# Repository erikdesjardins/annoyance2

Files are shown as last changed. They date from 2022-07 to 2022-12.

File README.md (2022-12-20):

# annoyance2

Digital musical tesla coil interrupter

Digital version of https://github.com/erikdesjardins/annoyance. Intended to run on a "blue pill" [STM32F103C8](https://www.st.com/resource/en/datasheet/stm32f103c8.pdf) board.

## Setup

Add the target corresponding to Cortex-M3:

```sh
rustup target add thumbv7m-none-eabi
```

Install tools for linking/flashing:

```sh
cargo install flip-link probe-run
```

Follow `probe-rs` docs to install drivers for flashing:

https://probe.rs/docs/getting-started/probe-setup/

## Development

### Run on device

```sh
# use `debug` or `trace` for more info
set DEFMT_LOG=info

cargo run --manifest-path firmware/Cargo.toml --target thumbv7m-none-eabi
```

### Run with visualizer

```sh
cargo run --manifest-path firmware/Cargo.toml --target thumbv7m-none-eabi --release | cargo run --manifest-path visualizer/Cargo.toml --release
```

### Misc

```
cargo objdump --release --bin main -- --disassemble --no-show-raw-insn --print-imm-hex
```

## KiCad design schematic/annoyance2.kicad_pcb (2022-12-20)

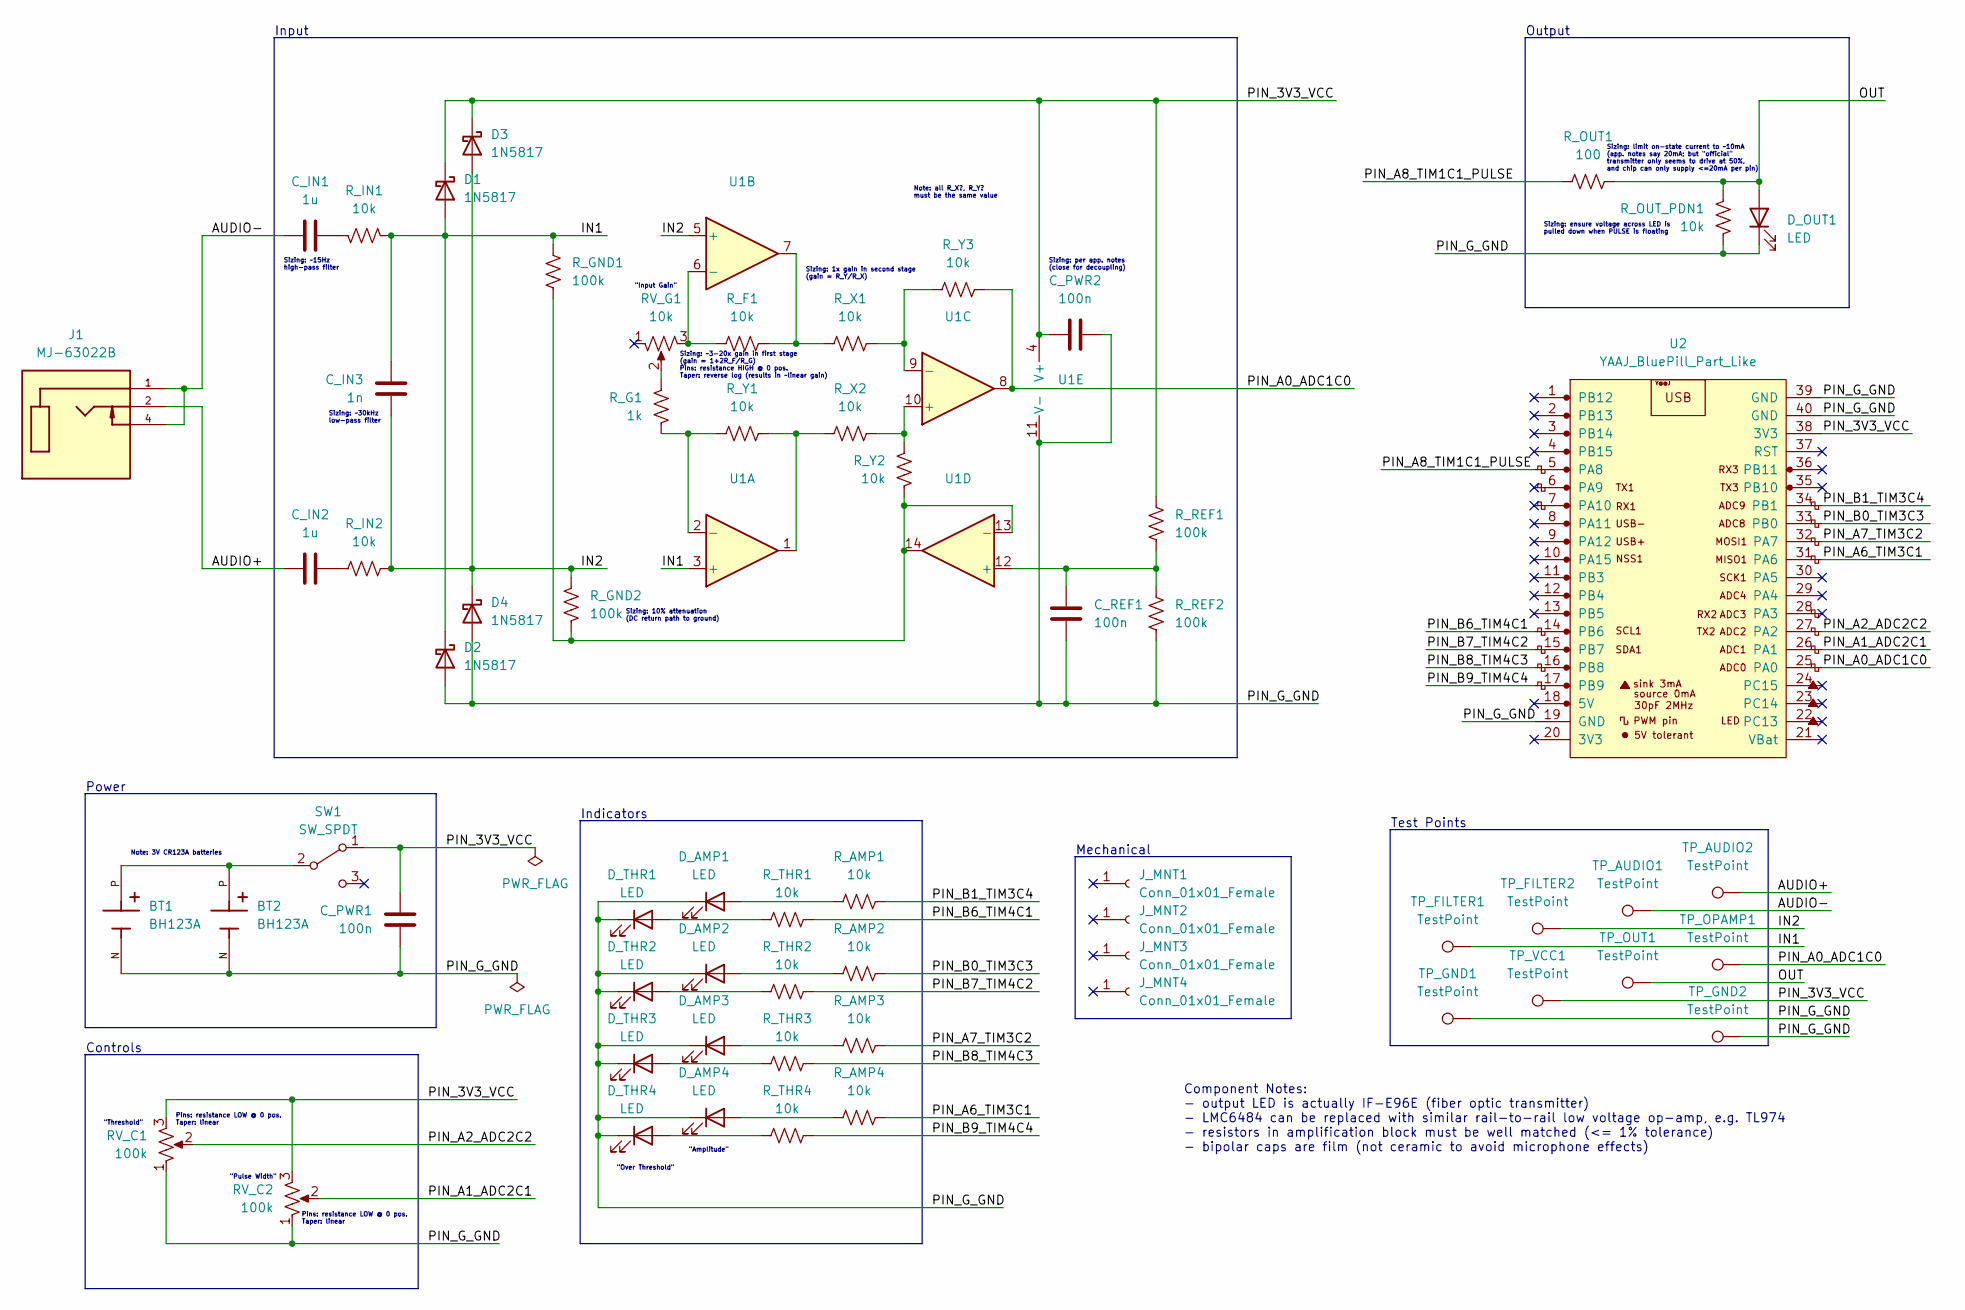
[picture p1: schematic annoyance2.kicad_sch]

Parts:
BT1, BT2: BH123A; BAT_BH123A; PARTREV E
C_IN1, C_IN2: 1u; C_Rect_L7.2mm_W5.5mm_P5.00mm_FKS2_FKP2_MKS2_MKP2
C_IN3: 1n; C_Rect_L7.2mm_W2.5mm_P5.00mm_FKS2_FKP2_MKS2_MKP2
C_PWR1, C_PWR2: 100n; C_Rect_L7.2mm_W2.5mm_P5.00mm_FKS2_FKP2_MKS2_MKP2
C_REF1: 100n; C_Rect_L7.2mm_W2.5mm_P5.00mm_FKS2_FKP2_MKS2_MKP2
D1, D2, D3, D4: 1N5817; D_DO-41_SOD81_P10.16mm_Horizontal
D_AMP1, D_AMP2, D_AMP3, D_AMP4: LED; LED_D5.0mm
D_OUT1: LED; IF-E96E
D_THR1, D_THR2, D_THR3, D_THR4: LED; LED_D5.0mm
J1: MJ-63022B; CUI_MJ-63022B; PARTREV 1.0
J_MNT1, J_MNT2, J_MNT3, J_MNT4: Conn_01x01_Female; MountingHole_3.2mm_M3_Pad
RV_C1, RV_C2: 100k; TRIM_PT01-D125D-B103
RV_G1: 10k; TRIM_PT01-D130D-A103
R_AMP1, R_AMP2, R_AMP3, R_AMP4: 10k; R_Axial_DIN0204_L3.6mm_D1.6mm_P5.08mm_Horizontal
R_F1: 10k; R_Axial_DIN0204_L3.6mm_D1.6mm_P5.08mm_Horizontal
R_G1: 1k; R_Axial_DIN0204_L3.6mm_D1.6mm_P5.08mm_Horizontal
R_GND1, R_GND2: 100k; R_Axial_DIN0204_L3.6mm_D1.6mm_P5.08mm_Horizontal
R_IN1, R_IN2: 10k; R_Axial_DIN0204_L3.6mm_D1.6mm_P5.08mm_Horizontal
R_OUT1: 100; R_Axial_DIN0204_L3.6mm_D1.6mm_P5.08mm_Horizontal
R_OUT_PDN1: 10k; R_Axial_DIN0204_L3.6mm_D1.6mm_P5.08mm_Horizontal
R_REF1, R_REF2: 100k; R_Axial_DIN0204_L3.6mm_D1.6mm_P5.08mm_Horizontal
R_THR1, R_THR2, R_THR3, R_THR4: 10k; R_Axial_DIN0204_L3.6mm_D1.6mm_P5.08mm_Horizontal
R_X1, R_X2: 10k; R_Axial_DIN0204_L3.6mm_D1.6mm_P5.08mm_Horizontal
R_Y1, R_Y2, R_Y3: 10k; R_Axial_DIN0204_L3.6mm_D1.6mm_P5.08mm_Horizontal
SW1: SW_SPDT; OS102011MA1Q
TP_AUDIO1, TP_AUDIO2: TestPoint; TestPoint_THTPad_2.0x2.0mm_Drill1.0mm
TP_FILTER1, TP_FILTER2: TestPoint; TestPoint_THTPad_2.0x2.0mm_Drill1.0mm
TP_GND1, TP_GND2: TestPoint; TestPoint_THTPad_2.0x2.0mm_Drill1.0mm
TP_OPAMP1: TestPoint; TestPoint_THTPad_2.0x2.0mm_Drill1.0mm
TP_OUT1: TestPoint; TestPoint_THTPad_2.0x2.0mm_Drill1.0mm
TP_VCC1: TestPoint; TestPoint_THTPad_2.0x2.0mm_Drill1.0mm
U1: (no value)
U2: YAAJ_BluePill_Part_Like; YAAJ_BluePill_1

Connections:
/AUDIO+: C_IN2.1, J1.2, TP_AUDIO2.1
/AUDIO-: C_IN1.1, J1.1, J1.4, TP_AUDIO1.1
/IN1: C_IN3.2, D1.2 (A), D2.1 (K), R_GND1.1, R_IN1.1, TP_FILTER1.1, U1.3 (+)
/IN2: C_IN3.1, D3.2 (A), D4.1 (K), R_GND2.1, R_IN2.2, TP_FILTER2.1, U1.5 (+)
/OUT: D_OUT1.2 (A), R_OUT1.2, R_OUT_PDN1.2, TP_OUT1.1
/PIN_3V3_VCC: C_PWR1.2, C_PWR2.1, D1.1 (K), D3.1 (K), RV_C1.3, RV_C2.3, R_REF1.1, SW1.1 (A), TP_VCC1.1, U1.4 (V+), U2.38 (3V3)
/PIN_A0_ADC1C0: R_Y3.2, TP_OPAMP1.1, U1.8, U2.25 (PA0)
/PIN_A1_ADC2C1: RV_C2.2, U2.26 (PA1)
/PIN_A2_ADC2C2: RV_C1.2, U2.27 (PA2)
/PIN_A6_TIM3C1: R_AMP4.2, U2.31 (PA6)
/PIN_A7_TIM3C2: R_AMP3.2, U2.32 (PA7)
/PIN_A8_TIM1C1_PULSE: R_OUT1.1, U2.5 (PA8)
/PIN_B0_TIM3C3: R_AMP2.2, U2.33 (PB0)
/PIN_B1_TIM3C4: R_AMP1.2, U2.34 (PB1)
/PIN_B6_TIM4C1: R_THR1.2, U2.14 (PB6)
/PIN_B7_TIM4C2: R_THR2.2, U2.15 (PB7)
/PIN_B8_TIM4C3: R_THR3.2, U2.16 (PB8)
/PIN_B9_TIM4C4: R_THR4.2, U2.17 (PB9)
/PIN_G_GND: BT1.N, BT2.N, C_PWR1.1, C_PWR2.2, C_REF1.1, D2.2 (A), D4.2 (A), D_AMP1.1 (K), D_AMP2.1 (K), D_AMP3.1 (K), D_AMP4.1 (K), D_OUT1.1 (K), D_THR1.1 (K), D_THR2.1 (K), D_THR3.1 (K), D_THR4.1 (K), RV_C1.1, RV_C2.1, R_OUT_PDN1.1, R_REF2.2, TP_GND1.1, TP_GND2.1, U1.11 (V-), U2.19 (GND), U2.39 (GND), U2.40 (GND)
unnamed: BT1.P, BT2.P, SW1.2 (B)
unnamed: C_IN1.2, R_IN1.2
unnamed: C_IN2.2, R_IN2.1
unnamed: C_REF1.2, R_REF1.2, R_REF2.1, U1.12 (+)
unnamed: D_AMP1.2 (A), R_AMP1.1
unnamed: D_AMP2.2 (A), R_AMP2.1
unnamed: D_AMP3.2 (A), R_AMP3.1
unnamed: D_AMP4.2 (A), R_AMP4.1
unnamed: D_THR1.2 (A), R_THR1.1
unnamed: D_THR2.2 (A), R_THR2.1
unnamed: D_THR3.2 (A), R_THR3.1
unnamed: D_THR4.2 (A), R_THR4.1
unnamed: RV_G1.2, R_G1.2
unnamed: RV_G1.3, R_F1.1, U1.6 (-)
unnamed: R_F1.2, R_X1.1, U1.7
unnamed: R_G1.1, R_Y1.1, U1.2 (-)
unnamed: R_GND1.2, R_GND2.2, R_Y2.1, U1.13 (-), U1.14
unnamed: R_X1.2, R_Y3.1, U1.9 (-)
unnamed: R_X2.1, R_Y1.2, U1.1
unnamed: R_X2.2, R_Y2.2, U1.10 (+)

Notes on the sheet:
Component Notes: - output LED is actually IF-E96E (fiber optic transmitter) - LMC6484 can be replaced with similar rail-to-rail low voltage op-amp, e.g. TL974 - resistors in amplification block must be well matched (<= 1% tolerance) - bipolar caps are film (not ceramic to avoid microphone effects)
Sizing: ~30kHz low-pass filter
"Over Threshold"
Controls
"Threshold"
Pins: resistance LOW @ 0 pos. Taper: linear
Input
Power
Sizing: limit on-state current to ~10mA (app. notes say 20mA; but "official" transmitter only seems to drive at 50%, and chip can only supply <=20mA per pin)
Output
Mechanical
Sizing: ensure voltage across LED is pulled down when PULSE is floating
Test Points
Indicators
Sizing: ~3-20x gain in first stage (gain = 1+2R_F/R_G) Pins: resistance HIGH @ 0 pos. Taper: reverse log (results in ~linear gain)
Sizing: ~15Hz high-pass filter
"Amplitude"
Sizing: 1x gain in second stage (gain = R_Y/R_X)
Note: all R_X?, R_Y? must be the same value
"Pulse Width"
Sizing: 10% attenuation (DC return path to ground)
Note: 3V CR123A batteries
"Input Gain"
Sizing: per app. notes (close for decoupling)

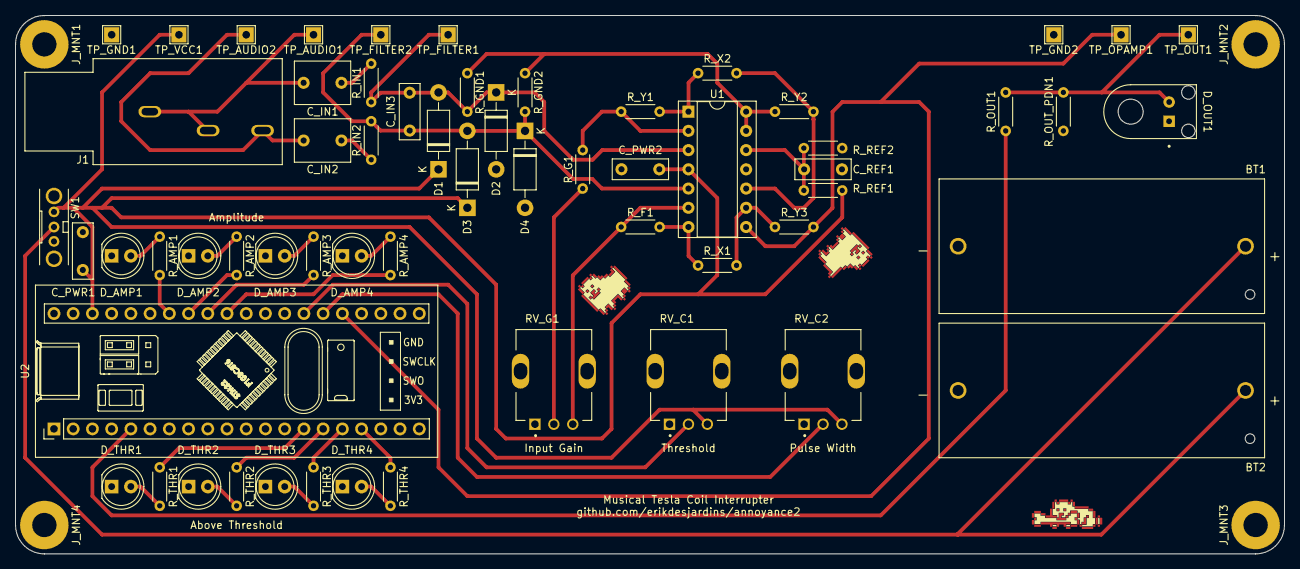
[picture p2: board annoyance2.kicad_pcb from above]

Board: 2 copper layers, 167.6 x 71.1 mm, 64 parts (0 on the bottom side), 39 nets.

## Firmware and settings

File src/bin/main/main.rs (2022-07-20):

#![no_main]
#![no_std]
#![allow(
    clippy::assertions_on_constants,
    clippy::let_and_return,
    clippy::let_unit_value,
    clippy::needless_range_loop,
    clippy::redundant_pattern_matching,
    clippy::type_complexity
)]
#![warn(
    clippy::cast_lossless,
    clippy::cast_possible_truncation,
    clippy::cast_possible_wrap,
    clippy::cast_sign_loss,
    clippy::ptr_as_ptr
)]

use annoyance2 as _; // global logger + panicking-behavior + memory layout

mod adc;
mod collections;
mod config;
mod control;
mod fft;
mod hal;
mod indicator;
mod math;
mod panic;
mod pulse;
mod time;

#[rtic::app(
    device = stm32f1xx_hal::pac,
    peripherals = true,
    dispatchers = [USART1, USART2, USART3]
)]
mod app {
    use crate::config;
    use crate::fft;
    use crate::hal::pins;
    use crate::hal::tim::{OnePulse, OneshotTimer};
    use crate::indicator;
    use crate::math::ScaleBy;
    use crate::panic::OptionalExt;
    use crate::pulse;
    use crate::pulse::{Pulses, UnadjustedPulses};
    use crate::time::{Duration, Instant, PulseDuration};
    use crate::{adc, control};
    use core::sync::atomic::{AtomicU32, Ordering};
    use cortex_m::singleton;
    use dwt_systick_monotonic::DwtSystick;
    use heapless::Vec;
    use stm32f1xx_hal::adc::{Adc, AdcDma, Continuous};
    use stm32f1xx_hal::device::{ADC1, TIM1, TIM3, TIM4};
    use stm32f1xx_hal::dma::{dma1, CircBuffer, Event};
    use stm32f1xx_hal::gpio::PinState;
    use stm32f1xx_hal::pac::ADC2;
    use stm32f1xx_hal::prelude::*;
    use stm32f1xx_hal::timer::{
        Ch, Channel::*, PwmHz, Tim1NoRemap, Tim3NoRemap, Tim4NoRemap, Timer,
    };

    static PULSE_WIDTH_TICKS: AtomicU32 = AtomicU32::new(0);

    #[shared]
    struct Shared {
        pulses: &'static mut Pulses,
    }

    #[local]
    struct Local {
        adc1_dma_transfer: CircBuffer<
            [u16; config::adc::BUF_LEN_RAW],
            AdcDma<ADC1, pins::A0_ADC1C0, Continuous, dma1::C1>,
        >,
        fft_buf: &'static mut [i16; config::fft::BUF_LEN_REAL],
        next_pulses: &'static mut UnadjustedPulses,
        adc2_controls: Adc<ADC2>,
        threshold_control_pin: pins::A2_ADC2C2,
        pulse_width_control_pin: pins::A1_ADC2C1,
        amplitude_timer: PwmHz<
            TIM3,
            Tim3NoRemap,
            (Ch<0>, Ch<1>, Ch<2>, Ch<3>),
            (
                pins::A6_TIM3C1,
                pins::A7_TIM3C2,
                pins::B0_TIM3C3,
                pins::B1_TIM3C4,
            ),
        >,
        threshold_timer: PwmHz<
            TIM4,
            Tim4NoRemap,
            (Ch<0>, Ch<1>, Ch<2>, Ch<3>),
            (
                pins::B6_TIM4C1,
                pins::B7_TIM4C2,
                pins::B8_TIM4C3,
                pins::B9_TIM4C4,
            ),
        >,
        pulse_timer:
            OnePulse<TIM1, Tim1NoRemap, Ch<0>, pins::A8_TIM1C1_PULSE, { config::clk::TIM1CLK_HZ }>,
        debug_led: pins::C13_DEBUG_LED,
    }

    #[init]
    fn init(mut cx: init::Context) -> (Shared, Local, init::Monotonics) {
        defmt::info!("Dumping config...");

        config::dump_to_log();

        defmt::info!("Starting init...");

        let mut afio = cx.device.AFIO.constrain();
        let dma1 = cx.device.DMA1.split();
        let mut flash = cx.device.FLASH.constrain();
        let mut gpioa = cx.device.GPIOA.split();
        let mut gpiob = cx.device.GPIOB.split();
        let mut gpioc = cx.device.GPIOC.split();
        let rcc = cx.device.RCC.constrain();

        defmt::info!("Configuring clocks...");

        let clocks = rcc
            .cfgr
            .use_hse(config::clk::HSE_FREQ)
            .sysclk(config::clk::SYSCLK)
            .pclk1(config::clk::PCLK1)
            .pclk2(config::clk::PCLK2)
            .adcclk(config::clk::ADCCLK)
            .freeze(&mut flash.acr);

        assert!(config::clk::SYSCLK == clocks.sysclk());
        assert!(config::clk::PCLK1 == clocks.pclk1());
        assert!(config::clk::PCLK2 == clocks.pclk2());
        assert!(config::clk::ADCCLK == clocks.adcclk());

        defmt::info!("Configuring ADC1 DMA transfer...");

        let mut dma1_ch1 = dma1.1;
        // Enable interrupts on DMA1_CHANNEL1
        dma1_ch1.listen(Event::HalfTransfer);
        dma1_ch1.listen(Event::TransferComplete);

        let mut adc1 = Adc::adc1(cx.device.ADC1, clocks);
        adc1.set_sample_time(config::adc::SAMPLE);

        let adc1_ch0: pins::A0_ADC1C0 = gpioa.pa0.into_analog(&mut gpioa.crl);

        let adc1_dma = adc1.with_dma(adc1_ch0, dma1_ch1);

        defmt::info!("Configuring ADC2 to read control values...");

        let adc2_controls = Adc::adc2(cx.device.ADC2, clocks);

        let threshold_control_pin: pins::A2_ADC2C2 = gpioa.pa2.into_analog(&mut gpioa.crl);
        let pulse_width_control_pin: pins::A1_ADC2C1 = gpioa.pa1.into_analog(&mut gpioa.crl);

        defmt::info!("Configuring amplitude indicator timer...");

        let tim3_ch4: pins::B1_TIM3C4 = gpiob.pb1.into_alternate_push_pull(&mut gpiob.crl);
        let tim3_ch3: pins::B0_TIM3C3 = gpiob.pb0.into_alternate_push_pull(&mut gpiob.crl);
        let tim3_ch2: pins::A7_TIM3C2 = gpioa.pa7.into_alternate_push_pull(&mut gpioa.crl);
        let tim3_ch1: pins::A6_TIM3C1 = gpioa.pa6.into_alternate_push_pull(&mut gpioa.crl);

        let mut amplitude_timer = Timer::new(cx.device.TIM3, &clocks).pwm_hz(
            (tim3_ch1, tim3_ch2, tim3_ch3, tim3_ch4),
            &mut afio.mapr,
            config::indicator::PWM_FREQ,
        );
        for ch in [C1, C2, C3, C4] {
            amplitude_timer.set_duty(ch, 0);
            amplitude_timer.enable(ch);
        }

        defmt::info!("Configuring threshold indicator timer...");

        let tim4_ch1: pins::B6_TIM4C1 = gpiob.pb6.into_alternate_push_pull(&mut gpiob.crl);
        let tim4_ch2: pins::B7_TIM4C2 = gpiob.pb7.into_alternate_push_pull(&mut gpiob.crl);
        let tim4_ch3: pins::B8_TIM4C3 = gpiob.pb8.into_alternate_push_pull(&mut gpiob.crh);
        let tim4_ch4: pins::B9_TIM4C4 = gpiob.pb9.into_alternate_push_pull(&mut gpiob.crh);

        let mut threshold_timer = Timer::new(cx.device.TIM4, &clocks).pwm_hz(
            (tim4_ch1, tim4_ch2, tim4_ch3, tim4_ch4),
            &mut afio.mapr,
            config::indicator::PWM_FREQ,
        );
        for ch in [C1, C2, C3, C4] {
            threshold_timer.set_duty(ch, 0);
            threshold_timer.enable(ch);
        }

        defmt::info!("Configuring pulse output timer...");

        let tim1_ch1: pins::A8_TIM1C1_PULSE = gpioa.pa8.into_alternate_push_pull(&mut gpioa.crh);

        let pulse_timer =
            OneshotTimer::new(cx.device.TIM1, &clocks).one_pulse_mode(tim1_ch1, &mut afio.mapr);

        defmt::info!("Configuring monotonic timer...");

        let mono = DwtMono::new(
            &mut cx.core.DCB,
            cx.core.DWT,
            cx.core.SYST,
            clocks.sysclk().to_Hz(),
        );

        defmt::info!("Configuring debug indicator LED...");

        let led: pins::C13_DEBUG_LED = gpioc
            .pc13
            .into_push_pull_output_with_state(&mut gpioc.crh, PinState::High);

        defmt::info!("Preparing buffers...");

        let adc_dma_buf =
            singleton!(: [[u16; config::adc::BUF_LEN_RAW]; 2] = [[0; config::adc::BUF_LEN_RAW]; 2])
                .unwrap();

        let fft_buf =
            singleton!(: [i16; config::fft::BUF_LEN_REAL] = [0; config::fft::BUF_LEN_REAL])
                .unwrap();

        let pulses = singleton!(: Pulses = Pulses::new()).unwrap();

        let next_pulses = singleton!(: UnadjustedPulses = UnadjustedPulses::new()).unwrap();

        defmt::info!("Starting ADC DMA transfer...");

        let adc1_dma_transfer = adc1_dma.circ_read(adc_dma_buf);

        defmt::info!("Finished init.");

        (
            Shared { pulses },
            Local {
                adc1_dma_transfer,
                fft_buf,
                next_pulses,
                adc2_controls,
                threshold_control_pin,
                pulse_width_control_pin,
                amplitude_timer,
                threshold_timer,
                pulse_timer,
                debug_led: led,
            },
            init::Monotonics(mono),
        )
    }

    // Task priorities
    //
    // Prio | Task         | Description
    //   16 | fire_pulse   | outputs pulses (triggered by timer interrupt)
    //   15 | DwtMono      | monotonic timer interrupt
    //   14 | swap_buffers | schedules pulse timing and processes ADC buffers
    //    0 | idle         | idle task

    /// This provides a monotonic timer used to trigger scheduled tasks.
    #[monotonic(
        binds = SysTick,
        priority = 15,
        default = true
    )]
    type DwtMono = DwtSystick<{ config::clk::SYSCLK_HZ }>;

    /// This task fires pulses.
    ///
    /// This task has the highest priority since any jitter will add phase noise to the output.
    #[task(
        shared = [
            pulses,
        ],
        local = [
            pulse_timer,
        ],
        priority = 16,
        capacity = 2 /* self + swap_buffers */,
    )]
    fn fire_pulse(mut cx: fire_pulse::Context, now: Instant) {
        cx.shared.pulses.lock(|pulses| {
            // consume this pulse (rescheduling this frequency)
            if let Err(()) = pulses.try_consume_pulse(now) {
                // if this pulse isn't present in the pulse train, our buffer was swapped,
                // and we've already been rescheduled
                defmt::trace!("pulse skipped due to in-flight buffer swap");
                return;
            }

            // load pulse width
            let pulse_width = PulseDuration::from_ticks(PULSE_WIDTH_TICKS.load(Ordering::Relaxed));

            // fire timer
            cx.local.pulse_timer.fire(pulse_width);
            if config::debug::LOG_ALL_PULSES {
                defmt::println!(
                    "Firing {}.{} us pulse at {} us",
                    pulse_width.to_nanos() / 1000,
                    pulse_width.to_nanos() % 1000,
                    Duration::from_ticks(now.ticks()).to_micros()
                );
            }

            // reschedule ourselves for the next pulse
            if let Some(next_pulse) = pulses.next_pulse(now) {
                if let Err(_) = fire_pulse::spawn_at(next_pulse, next_pulse) {
                    defmt::warn!("fire_pulse schedule overrun");
                }
            }
        });
    }

    /// This task schedules pulse timings, from the previous buffer,
    /// to be emitted while processing the current buffer.
    ///
    /// Ideally, we would like this task to have no jitter,
    /// so that timings are computed based on a consistent interval.
    ///
    /// However, this isn't perfectly feasible, since `fire_pulse` needs to be higher priority.
    ///
    /// Note that even having the highest priority would not guarantee lack of jitter:
    /// resource locks can introduce jitter when a lower-priority task takes the lock.
    #[task(
        binds = DMA1_CHANNEL1,
        shared = [
            pulses,
        ],
        local = [
            adc1_dma_transfer,
            fft_buf,
            next_pulses,
            adc2_controls,
            threshold_control_pin,
            pulse_width_control_pin,
            amplitude_timer,
            threshold_timer,
            debug_led,
        ],
        priority = 14,
    )]
    fn swap_buffers(mut cx: swap_buffers::Context) {
        cx.local.debug_led.set_low();

        // getting the timestamp must happen a consistent delay after the start of the task,
        // so timing is consistent
        let start = monotonics::now();
        // ...after this point, even if there is variable latency / jitter,
        //    everything will be scheduled off of that timestamp.

        // Note that we still need to start scheduling pulses quickly, however,
        // because delays could result in pulses being scheduled in the past.

        // Phase 1: swap in new pulse train and reschedule

        // Step 1: adjust pulses and swap
        let next_pulse = cx.shared.pulses.lock(|pulses| {
            pulses.replace_with_adjusted(cx.local.next_pulses, start);
            pulses.next_pulse(start)
        });

        // Step 2: schedule task for next pulse
        if let Some(next_pulse) = next_pulse {
            if let Err(_) = fire_pulse::spawn_at(next_pulse, next_pulse) {
                defmt::warn!("fire_pulse schedule overrun (from swap_buffers2)");
            }
        }

        let mid = monotonics::now();
        if config::debug::LOG_TIMING {
            defmt::println!(
                "Finished scheduling new pulses after {}us",
                (mid - start).to_micros()
            );
        }

        // Phase 2: update current values of controls

        // Step 1: read from controls
        let amplitude_threshold = {
            let sample = cx
                .local
                .adc2_controls
                .read(cx.local.threshold_control_pin)
                .unwrap_infallible();
            control::adc_sample_to_value_in_range(
                sample,
                config::fft::analysis::AMPLITUDE_THRESHOLD_RANGE,
            )
        };
        let pulse_width = {
            let sample = cx
                .local
                .adc2_controls
                .read(cx.local.pulse_width_control_pin)
                .unwrap_infallible();
            control::adc_sample_to_value_in_range_via(
                sample,
                config::pulse::DURATION_RANGE,
                |d| d.ticks(),
                PulseDuration::from_ticks,
            )
        };

        // Step 2: store pulse width
        PULSE_WIDTH_TICKS.store(pulse_width.ticks(), Ordering::Relaxed);

        // Step 3: log control values
        if config::debug::LOG_CONTROL_VALUES {
            defmt::println!("Amplitude threshold: {}", amplitude_threshold);
            defmt::println!(
                "Pulse width: {}.{} us",
                pulse_width.to_nanos() / 1000,
                pulse_width.to_nanos() % 1000
            );
        }

        // Phase 3: process current ADC buffer to prepare for the next swap

        let res = cx.local.adc1_dma_transfer.peek(|samples, _| {
            let scratch = cx.local.fft_buf;

            let (values, padding) = scratch.split_at_mut(config::adc::BUF_LEN_PROCESSED);
            let values: &mut [_; config::adc::BUF_LEN_PROCESSED] =
                values.try_into().unwrap_infallible();

            // Step 0: compute and display amplitude from raw samples
            let amplitude_factors = indicator::amplitude_scaling_factors(samples);
            for (factor, ch) in amplitude_factors.into_iter().zip([C4, C3, C2, C1]) {
                let duty = cx.local.amplitude_timer.get_max_duty().scale_by(factor);
                cx.local.amplitude_timer.set_duty(ch, duty);
            }

            // Step 1: populate values and padding in FFT scratch buffer
            adc::process_raw_samples(samples, values);
            padding.fill(0);

            // Step 2: apply window function to data
            fft::window::apply_to(values);

            // Step 3: run fft
            let bins = fft::run(scratch);

            // Step 4: find peaks in spectrum
            let mut peaks = Vec::new();
            fft::analysis::find_peaks(bins, amplitude_threshold, &mut peaks);

            // Step 5: compute pulses based on peaks
            pulse::schedule_pulses(&peaks, cx.local.next_pulses);

            // Step 6: compute and display "above threshold" from peaks
            let threshold_factors =
                indicator::threshold_scaling_factors(&peaks, amplitude_threshold);
            for (factor, ch) in threshold_factors.into_iter().zip([C1, C2, C3, C4]) {
                let duty = cx.local.threshold_timer.get_max_duty().scale_by(factor);
                cx.local.threshold_timer.set_duty(ch, duty);
            }
        });

        let duration = monotonics::now() - mid;
        match res {
            Ok(()) => {
                if config::debug::LOG_TIMING {
                    defmt::println!(
                        "Finished processing ADC buffer after {}us.",
                        duration.to_micros()
                    );
                }
            }
            Err(_) => {
                defmt::warn!(
                    "ADC buffer processing did not complete in time (took {}us).",
                    duration.to_micros()
                );
            }
        }

        cx.local.debug_led.set_high();
    }

    #[idle]
    fn idle(_: idle::Context) -> ! {
        loop {
            // Note that using `wfi` here breaks debugging,
            // so if desired we should only do that in release mode.
            continue;
        }
    }
}

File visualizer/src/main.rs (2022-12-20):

use crossterm::event::{Event, KeyCode, KeyModifiers};
use crossterm::terminal::{
    disable_raw_mode, enable_raw_mode, EnterAlternateScreen, LeaveAlternateScreen,
};
use crossterm::{event, execute};
use std::io::{self, BufRead};
use std::thread;
use tui::backend::CrosstermBackend;
use tui::Terminal;
use visualizer::defer;
use visualizer::err;
use visualizer::parse;
use visualizer::state::State;
use visualizer::terminal::{self, Redraw};

fn main() -> Result<(), err::DebugFromDisplay<io::Error>> {
    if atty::is(atty::Stream::Stdin) {
        eprintln!(
            r"Input must be piped into stdin.

All available commands:
.vz <id> cn <chart name>
.vz <id> sn <series name>
.vz <id> xn <x-axis name>
.vz <id> yn <y-axis name>
.vz <id> xr <x-axis min> <x-axis max>
.vz <id> yr <y-axis min> <y-axis max>
.vz <id> xs [<x coord>, ...]
.vz <id> ys [<y coord>, ...]

Note: `xr`/`yr` will automatically fit the data.
Note: `xs` doesn't need to be resent every time.

Example sequence:
.vz cn 0 FFT
.vz xn 0 Frequency
.vz yn 0 Amplitude
.vz xs 0 [0, 10, 20, 40, 80]
.vz ys 0 [10, 12, 20, 14, 8]
.vz ys 0 [11, 13, 19, 14, 7]"
        );
        return Ok(());
    }

    let stdout = io::stdout();
    let mut stdin = io::stdin().lock();

    let mut terminal = Terminal::new(CrosstermBackend::new(&stdout))?;

    thread::scope(|s| {
        // spawn a background thread to handle user input (for exiting)
        s.spawn(|| {
            let status = {
                defer! { let _ = disable_raw_mode(); }
                defer! { let _ = execute!(&stdout, LeaveAlternateScreen); }

                fn run() -> Result<(), io::Error> {
                    loop {
                        if let Event::Key(key) = event::read()? {
                            let ctrl_c = key.modifiers == KeyModifiers::CONTROL
                                && key.code == KeyCode::Char('c');
                            if ctrl_c {
                                return Ok(());
                            }
                        }
                    }
                }

                match run() {
                    Ok(()) => 0,
                    Err(e) => {
                        eprintln!("Failed to run input thread: {:?}", e);
                        1337
                    }
                }
            };

            std::process::exit(status);
        });

        let mut state = State::default();
        let mut line = String::new();

        // Wait for first line of input before we switch to the alt screen.
        // This helps in situations like `cargo run firmware | cargo run visualizer`,
        // where the firmware is still building (and hence writing to the screen),
        // so it doesn't stomp on the graph.
        if stdin.read_line(&mut line)? == 0 {
            // input stream closed
            return Ok(());
        }

        // We've seen our first line of input--switch to the alt screen and start rendering.
        enable_raw_mode()?;
        defer! { let _ = disable_raw_mode(); }
        execute!(&stdout, EnterAlternateScreen)?;
        defer! { let _ = execute!(&stdout, LeaveAlternateScreen); }
        terminal.hide_cursor()?;

        loop {
            // Parse line
            let redraw = parse::handle_line(&mut state, &line);

            // Redraw if requested
            match redraw {
                Redraw::No => {}
                Redraw::Yes => terminal::draw(&state, &mut terminal)?,
            }

            // Read next line
            line.clear();
            if stdin.read_line(&mut line)? == 0 {
                // input stream closed
                return Ok(());
            }
        }
    })
}

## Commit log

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2022-05-16 configure pwm output for use as a virtual ground at Vcc/2
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2022-05-25 tweak copying samples from input to scratch buffer
2022-05-25 add simple board schematic
    [annoyance2.kicad_pcb, annoyance2.kicad_sch]
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2022-05-25 use debug led to visualize adc buffer processing
2022-05-26 enable clippy lints related to cast/truncation and fix issues
    [adc.rs, config.rs, main.rs]
2022-05-26 introduce and use unwrap_infallible for known-correct unwraps (with optimizations)
    [adc.rs, main.rs]
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2022-05-26 fix frequency binning calculation with complex fft samples
    [adc.rs, config.rs, main.rs]
2022-05-26 tweak ADC sample rate
    ~4x lower ADC clock, slightly higher sample rate
    i hypothesize that a lower ADC clock will improve accuracy, but it's hard to tell
2022-05-26 switch protection diodes out for schottkys, per app. notes
    [annoyance2.kicad_sch]
2022-05-26 remove debug logging of final samples
    it's not that useful, now that i know it is in fact copying data correctly
    [adc.rs, config.rs]
2022-05-27 put back 1k resistor on reference voltage
    [annoyance2.kicad_sch]
2022-05-28 use 1uF cap for DC path to ground
    since we don't have a buffer or anything for the mid-rail voltage
    [annoyance2.kicad_sch]
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2022-05-28 add debug option to fake input data from adc
2022-05-28 move debug flags to separate file
    this should make it harder to accidentally commit flips of debug flags when there are other (desired) config changes
    [config.rs]
2022-05-29 add ability to set phase of fake input, and use cos instead of sin
    looks like the fft bases its initial phase on cos
    this works better for us anyways, since we want to trigger the coil to fire on peaks, and cos peaks at 0 phase, which is perfect
    while testing this, i can tell that the phase calculation is correct-ish -- shifting the phase by pi/2 at a time does shift the resulting phase
    BUT, there seems to be a constant ~40deg offset, which is weird...
    thankfully a constant offset shouldn't impact the functioning of this device -- it may result in different frequencies being in different relative phases compared to each other, but i don't think the human ear can detect that
    [adc.rs]
2022-05-29 physically separate ADC pins, put pwm reference between them
    injection current in adjacent pins can negatively affect the adc; leaving a gap between pins will help mitigate this
    noise from nearby pwms can impact the adc as well; putting the pwm in the middle should ensure that both channels are equally impacted (and hence cancelled out in the difference)
    [annoyance2.kicad_sch]
2022-05-29 add smoothing caps on reference voltage and across the rails, change back to 10k on voltage reference
    [annoyance2.kicad_sch]
2022-05-29 add component notes to schematic
    [annoyance2.kicad_sch]
2022-05-30 explain why we expect adc difference truncation to always fit
2022-05-31 significantly improve peak frequency adjustment by linearly interpolating based on three nearest points
    this is _almost_ perfect, although there's a bit of nonlinearity near midpoints, it might be off by ~1Hz
2022-06-02 fix frequencies being doubled
    i guess the sampling rate gets halved twice--both by the usual nyquist halving (showing up as the FFT having two halves, for positive and negative frequencies), but also by converting each pair of samples to a single complex sample
    [config.rs]
2022-06-02 fix adc conversion time calculation (fixing frequencies being off by ~25%)
    needed to include an additional 12.5 cycles for successive approximation
    always read the fine print...
    [config.rs]
2022-06-02 adjust adc sample rate back up to ~40kHz, after accounting for additional 12.5 cycles latency
2022-06-02 avoid overflow in sample cycles calculation when oversampling
    [config.rs]
2022-06-02 enable 2x oversampling
    this doesn't really seem necessary (there isn't noticeably less noise when enabling this, and the signal is pretty clean already)
    but why not. it only costs ~1k
    [config.rs]
2022-06-06 consolidate `fixed`/`num` modules into `math`, make `scale_by` a trait
    [adc.rs, main.rs, window.rs]
2022-06-07 WIP: complex task scheduling (with less jitter)
    this has less jitter in theory, since it uses the highest-priority task (with no locks that could potentially block it) to fetch the timestamp
    however, it needs to be triggered by the DMA interrupt, and will be reinvoked repeatedly until the interrupt request is cleared.
    this could be done, although it would be pretty janky, so i won't
    instead, i'll make the DMA interrupt (where the buffer is batch-processed) compute the timestamp, which will add jitter / phase noise, but hopefully not a huge amount
    [config.rs, main.rs, tim.rs]
2022-06-07 simpler pulse scheduling, with more jitter/phase noise, but that should actually work
    [config.rs, main.rs]
2022-06-15 tweak layout of filtering caps on schematic
    [annoyance2.kicad_sch]
2022-06-16 fix timer enabling
    (TIM1 needs the AOE automatic output enable bit set)
    [tim.rs]
2022-06-16 add pulldown across output LED
    since the timer output pin floats when not configured
    [annoyance2.kicad_sch]
2022-06-17 add analog preamplification stage
    the input amplitude from a guitar (or even a headphone jack) is just too low to reliably detect.
    i wanted to avoid this for circuit complexity reasons, but it's (unfortunately? fortunately?) necessary
    this does have some major benefits though--
    first, the instrumentation amplifier naturally converts the differential input to single-ended, allowing us to halve the input buffer size and avoid doing the differential subtraction in software
    second, this lets us use a real buffer for the virtual ground, which should be much more stable than filtered pwm
    third, this gives us easily adjustable gain, which is useful, and avoids the question of how exactly to tune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
    [annoyance2.kicad_sch]
2022-06-18 add symbol/footprint for devboard, add batteries, reverse log pot (and control pots), etc.
    [annoyance2.kicad_sch]
2022-06-22 initial pcb layout
    [annoyance2.kicad_sch]
2022-06-22 add indicator LEDs
    [annoyance2.kicad_pcb, annoyance2.kicad_sch]
2022-06-22 align some components more symmetrically, make some tracks a bit nicer
    [annoyance2.kicad_pcb]
2022-06-22 add one more power filtering cap
    [annoyance2.kicad_pcb, annoyance2.kicad_sch]
2022-06-22 tweak more tracks
    [annoyance2.kicad_pcb]
2022-06-22 more tweaks
    [annoyance2.kicad_pcb]
2022-06-23 add mounting holes and round pcb corners
    [annoyance2.kicad_pcb, annoyance2.kicad_sch]
2022-06-23 add test points
    [annoyance2.kicad_pcb, annoyance2.kicad_sch]
2022-06-24 tweak more traces
    [annoyance2.kicad_pcb]
2022-06-24 remove center mounting hole
    it's quite ugly, and it's not necessary
    if we need physical support under the middle of the board, we can just put a support there without going through the board--
    we'll have enough horizontal positioning from the corner mounting points
    [annoyance2.kicad_pcb, annoyance2.kicad_sch]
2022-06-29 add annoying dog silkscreen/trace art
    [annoyance2.kicad_pcb]
2022-06-29 properly segment a branching track
    (this helps the track rounding plugin work properly)
    [annoyance2.kicad_pcb]
2022-07-04 add pixel art with proper clearance (generated with silkgen)
    [annoyance2.kicad_pcb]
2022-07-04 tweak some more track connections to work better with track rounding
    [annoyance2.kicad_pcb]
2022-07-05 power consumption: use 10k pots for adjustments
    (these could even be 100k, but i only ordered 1k and 10k pots...)
    [annoyance2.kicad_pcb, annoyance2.kicad_sch]
2022-07-05 power consumption: use 10k resistors/pots around opamp gain stage
    can't go higher than this without risking instability
    (unless we switch to a lower-performance opamp)
    [annoyance2.kicad_pcb, annoyance2.kicad_sch]
2022-07-05 power consumption: remove output pullup, make pulldown much larger
    the "official" interrupter doesn't have a pullup; it's hard to tell whether it actually makes the output switch faster; and it draws power continuously
    [annoyance2.kicad_pcb, annoyance2.kicad_sch]
2022-07-07 power consumption: 10k resistors on indicator LEDs
    [annoyance2.kicad_pcb, annoyance2.kicad_sch]
2022-07-07 power consumption: 100k resistors on Vcc/2 voltage reference
    [annoyance2.kicad_pcb, annoyance2.kicad_sch]
2022-07-07 power consumption: 100k adjustment pots
    [annoyance2.kicad_pcb, annoyance2.kicad_sch]
2022-07-13 fix off-by-one in adjustment of ADC samples to Vcc/2
    [adc.rs, config.rs]
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2022-07-20 fix amplitude indicator calculation
    [indicator.rs]
2022-07-20 fix swapped pads on transmitter
    the footprint in the datasheet is actually the BOTTOM, so everything is mirrored >:(
    thankfully there is physical space inside the component, so i can cross over the leads to make it work on my existing board...
    [annoyance2.kicad_pcb]
2022-07-20 reduce cpu clock from 72 MHz to 24 MHz
    this greatly reduces power consumption, since most of the power during operation is consumed by the micro
2022-07-22 increase clock slightly to 32MHz
    24MHz is not quite enough to avoid buffer overruns
    [config.rs]
2022-07-22 improve scheduling consistency, cancel any inflight pulse when swapping buffers
    [main.rs]
2022-07-22 increase scheduling offset / holdoff to 50us to avoid popping
    when this is too low, pulses can get scheduled too close together
    which effectively creates one long pulse, causing a higher-amplitude pop
    [config.rs]
2022-07-23 scale up ADC samples to full u16 range to preserve more precision in FFT
    this makes a _huge_ difference in clarity/SNR
2022-07-23 change threshold control to be a percentage of the highest peak
    this should work a lot better than a fixed point--
    it effectively gives us "automatic gain control", culling lower amplitudes when the highest peak is louder, and allowing lower amplitudes when the highest peak is softer
    it also means that much more of the range of the amplitude control is useful, which is a nice bonus
    since giving an amplitude value for the threshold indicator doesn't make much sense anymore (since it would be pretty proportional to the input amplitude),
    that indicator now displays the polyphony, i.e. the number of peaks above the threshold, which is also something i wanted to see (funny how that works...)
    [config.rs, indicator.rs, main.rs]
2022-07-24 switch to opt-level=2/3 instead of opt-level=s
    this increases binary size by 20% in release (5% in debug), which we can afford, while providing significant perf improvements:
    debug mode batch processing drops from 22ms to 18ms, and release mode pulse scheduling drops from 5us to 3us
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2022-07-25 adjust frequency back up to 48MHz
    this is enough to avoid any overruns, even with ...strenuous... inputs
    it also brings the max possible fft frequency down a bit, to about C8 (roughly the highest note a violin can play in the extreme)
    we really don't want to be reproducing anything higher than that
    [config.rs]
2022-08-04 switch to rail-to-rail opamp
    3V is such a low supply voltage that we need all the range we can get
    the TLC074 and similar op-amps are unable to use something on the order of 0.7V of the supply span, which is huge at 3V
    [annoyance2.kicad_pcb, annoyance2.kicad_sch]
2022-08-08 implement FFT amplitude equalization
    this seems like it shouldn't be necessary...it's quite hard to search for, but i can't find anyone else mentioning a non-flat frequency response from an FFT
    and it doesn't make sense--it would make extracting amplitudes from an FFT meaningless if there was some falloff at high frequencies
    (i would at least expect one of the FFT implementation papers i've seen to mention correcting for this, if it is a thing)
    note for posterity: this happens even with a generated input with no window function. so it really seems like a problem specifically with the FFT, and not with anything else
    (there is about 10% attenuation at 4kHz vs. 40Hz, from the input filtering,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
    [adc.rs, config.rs, main.rs]
2022-09-22 switch to collecting all peaks in a buffer
    to enable easier experimentation, e.g. with combining harmonics together
2022-12-12 visualizer: remove unnecessary polling timeout
    we can just block on this event, since this is a separate thread anyways
2022-12-13 firmware: log 512 adc samples by default
    this works better with the visualizer
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
